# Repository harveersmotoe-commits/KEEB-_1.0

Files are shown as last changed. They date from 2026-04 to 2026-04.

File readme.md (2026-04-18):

# Description:

This is a 60% keyboard which also has a rotary encoder, 0.91 oled display, and 5 extra programmable buttons. This runs on a Raspberry Pi Pico and is not battery powered. 

Why did I make this?
In blueprint I had tried to make a split keyboard because in my opinion that is way cooler than this, the only thing being that it was kinda difficult without any piror knowledge. You can kind of spot the attempt in the schematics but, I did ditch it soon after. 

# Schematics



# PCB



# 3d Renders: 

https://cad.onshape.com/documents/1ae3be99bbc461a973191d69/w/fc64a29f0eed5ccd2d31274e/e/07f126c9bb32923463e6050c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

FRONT:



SIDE:



# Zine Fallout Page

# BOM



# CREDITS

Hack Club Fallout: For giving me this oppurtunity

Thanks to the Youtube Creator Flux (For the tips on how to make my PCB look presentable)

# How to Build

  Start off with the Raspberry Pi and Solider headers if not yet soldier, if you are a beginner I would highly recommend watching this video (https://youtu.be/Z0joOKaQ43A?si=yZU-sQ1wUjgkzB4q&t=37)

  Then add switches to all of the holes that ressemble hole puncher holes, making sure that the little copper lines aren't being jammed in the wrong way, this should be easy to put on with not much resistance.

  After doing this solder all the switches to the pcb and then follow with the Raspberry Pi Pico and resistors (Photo coming soon of where to put what)

  NOTE: FOR UNDERGLOW MAKE SURE YOU ORDER THE RIGHT PCB (ONE HAS NO SUPPORT) AND USE CLEAR FILAMENT FOR THE BOTTOM SHELL IF USING UNDERGLOW

  *If you have the PCB WHICH HAS UNDERGLOW SUPPORT MAKE SuRE YOU SOLDIER THE LEDS TO THE BOTTOM

  Then grab your 3d printed materials and use the screws to tighten the pcb to the bottom shell

  Use the magnets and add them onto both the bottom and top shell pieces.

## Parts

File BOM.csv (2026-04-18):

 |  | QTY | PRICE
Raspberry Pi: | https://www.alibaba.com/product-detail/Stock-original-Raspberry-Pi-Pico-W_1601212449258.html | 1 | $2.87
0.91 OLED: | https://www.aliexpress.us/item/3256806882812437.html | 1 | $2.15
Keycaps | https://www.alibaba.com/product-detail/Rene-Genger-129-Keys-Side-Printed_1601675107935.htmll | 1 | $9.28
Diodes | https://www.aliexpress.us/item/3256802153601411.html | 1 | $1.04
Buttons: | https://www.aliexpress.us/item/3256808426699412.html | 4 | $3.01
Stabillizers: | https://www.aliexpress.us/item/3256807026554334.html | 1 | $0.99
Capaciators: | https://www.aliexpress.us/item/3256807473764027.html | 1 | $0.99
LEDs; | https://www.aliexpress.us/item/2255801159561004.html | 1 | $0.99
Capacators: | https://www.aliexpress.us/item/3256802104127109.html | 1 | $1.30
PCB | I ORDERED FROM JLCPCB (CHEAPER THAN PCBWAY IN CALI) | 1 | $19.10
Plate (3D Printed) |  | 1 | N/A
Magnets: | https://www.aliexpress.us/item/3256811570240902.htmll | 1 | $0.99
Keyswitches | https://www.aliexpress.us/item/3256808499657735.html | 1 | $5.57
Shells (3D printed) |  | 1 | N/A
 |  | TOTAL | $59.59

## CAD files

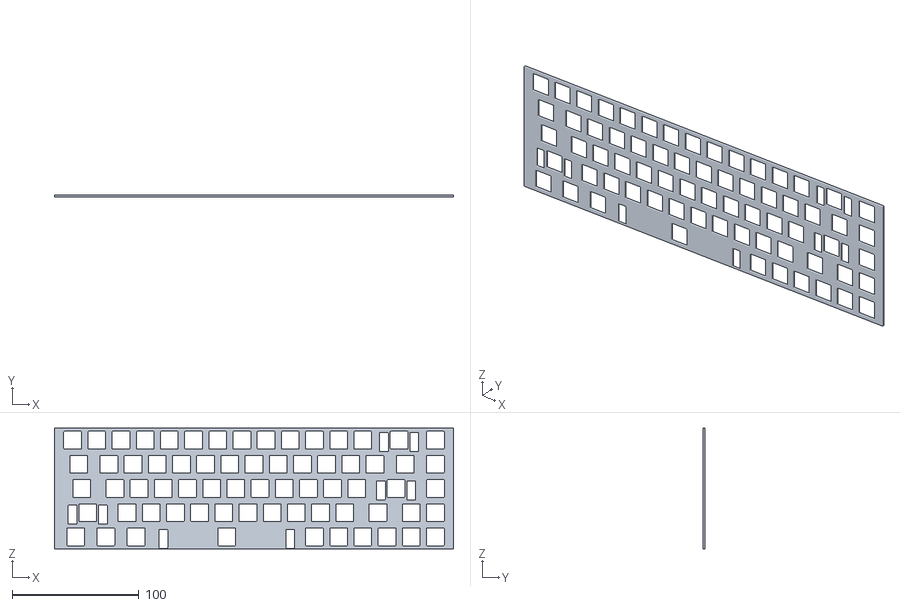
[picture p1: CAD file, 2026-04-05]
STLS/Keeb Plate.stl
314.3 x 1.60 x 95.2

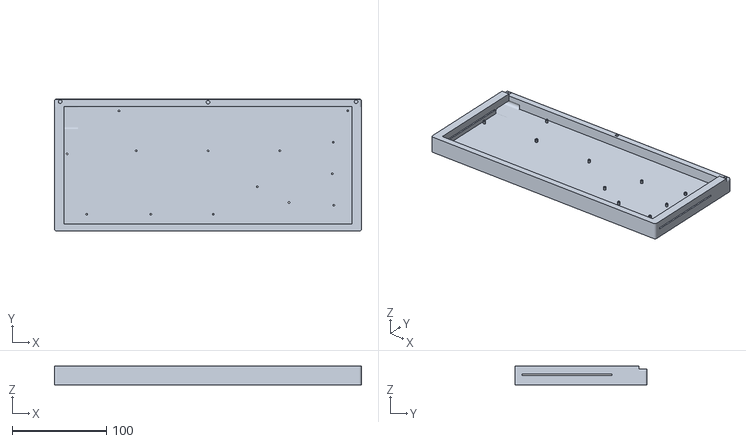
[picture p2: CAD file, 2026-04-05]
STLS/KeebBase.stl
325.0 x 140.0 x 20.0

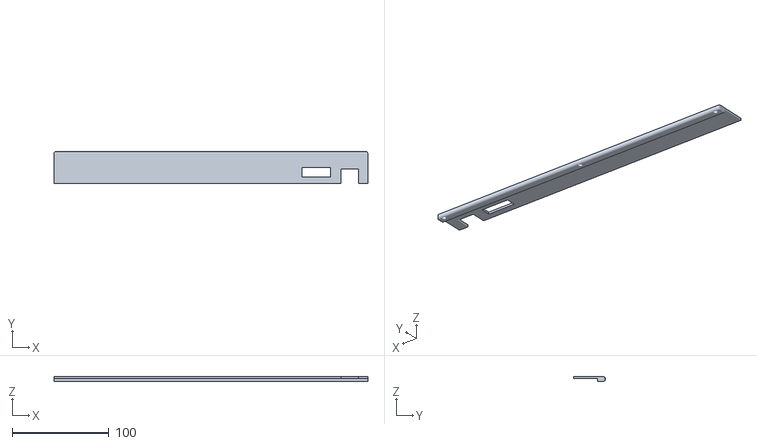
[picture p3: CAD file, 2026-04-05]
STLS/KEEBtop (1).stl
325.0 x 33.2 x 5.00

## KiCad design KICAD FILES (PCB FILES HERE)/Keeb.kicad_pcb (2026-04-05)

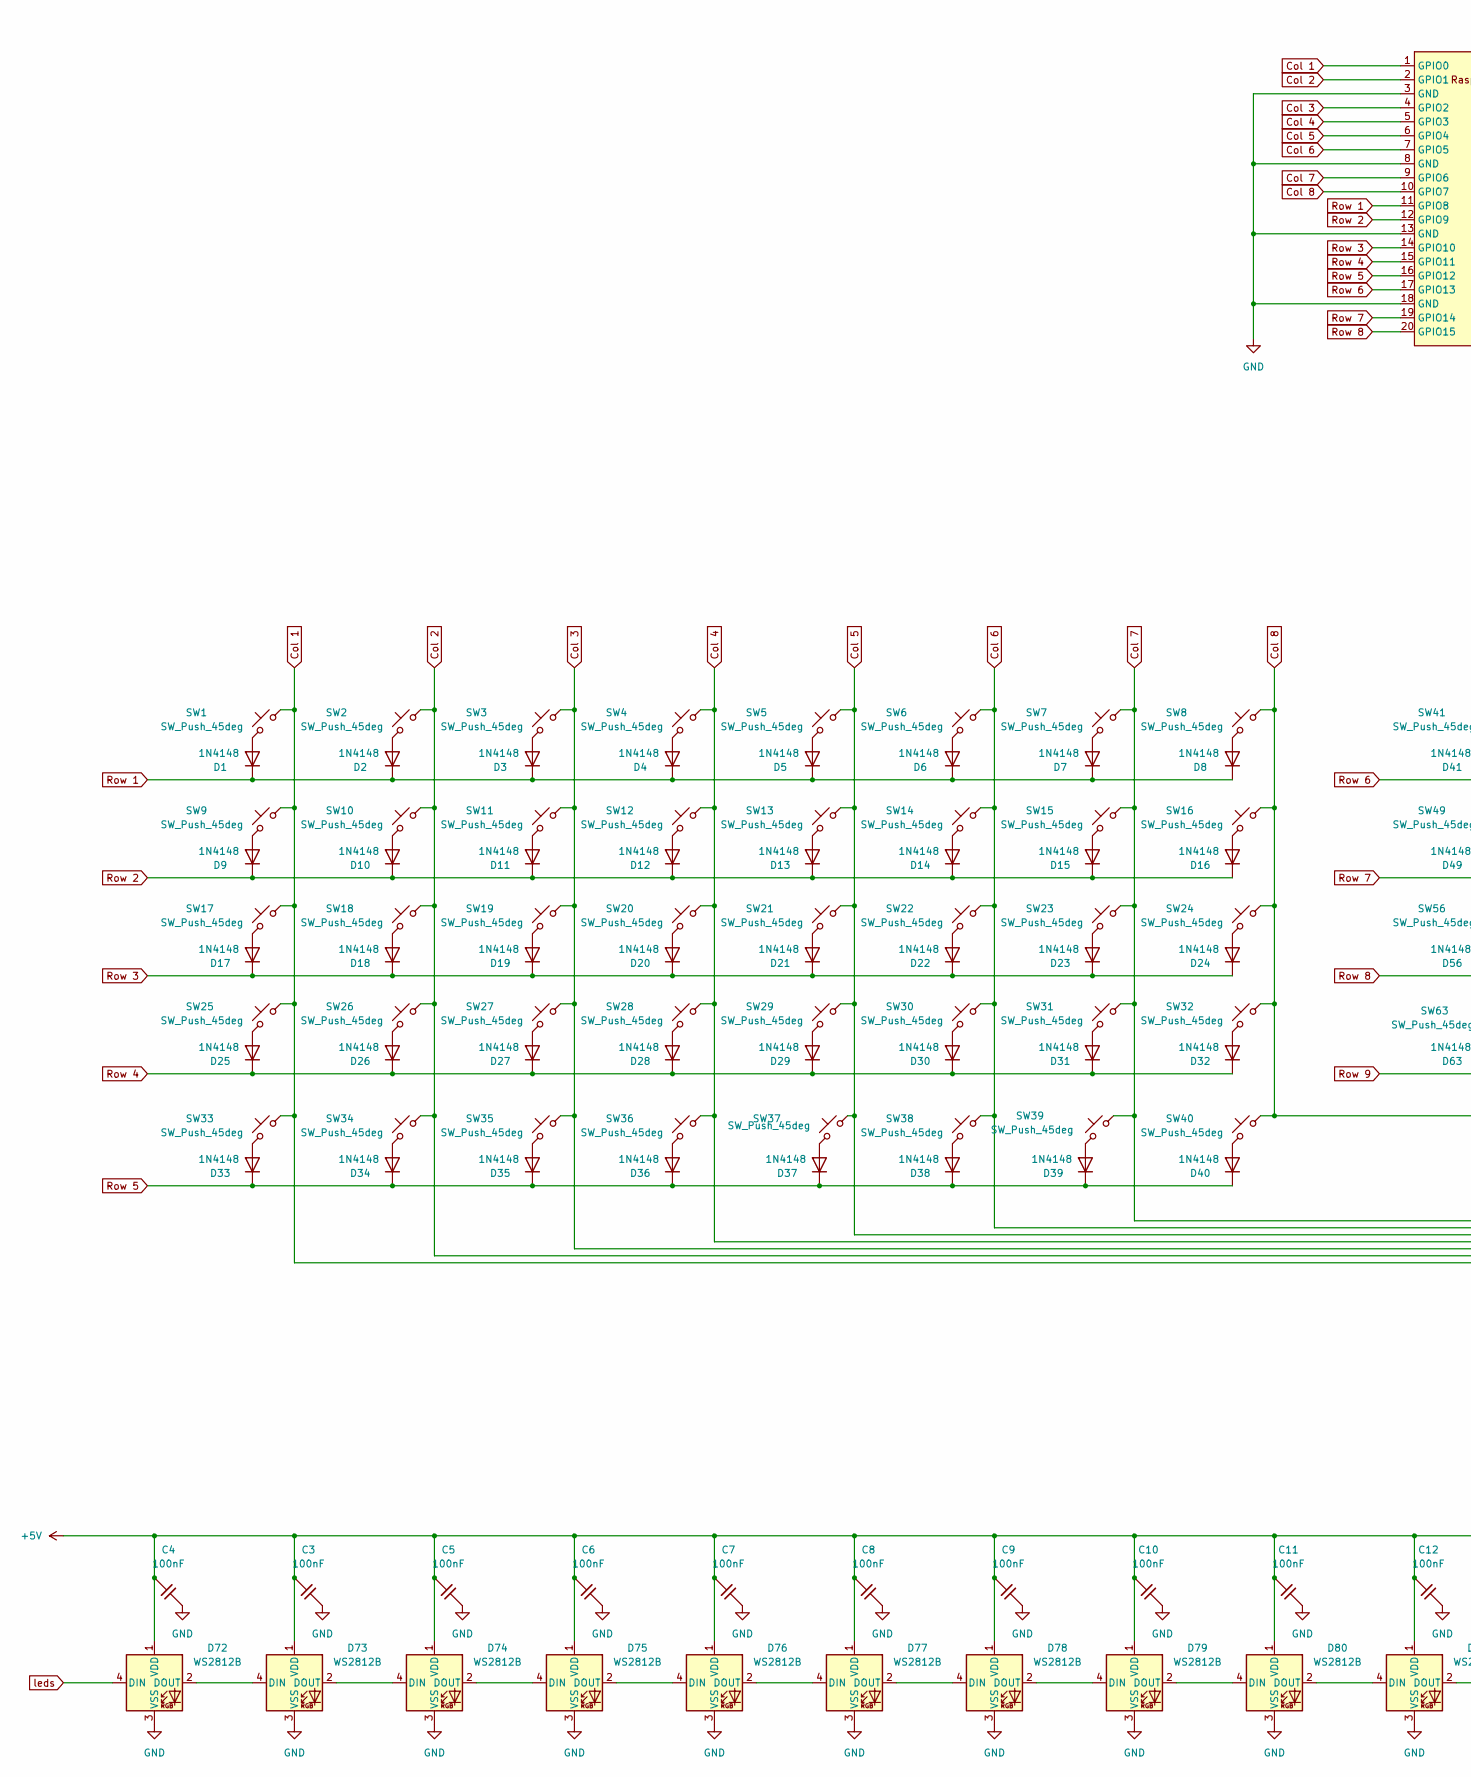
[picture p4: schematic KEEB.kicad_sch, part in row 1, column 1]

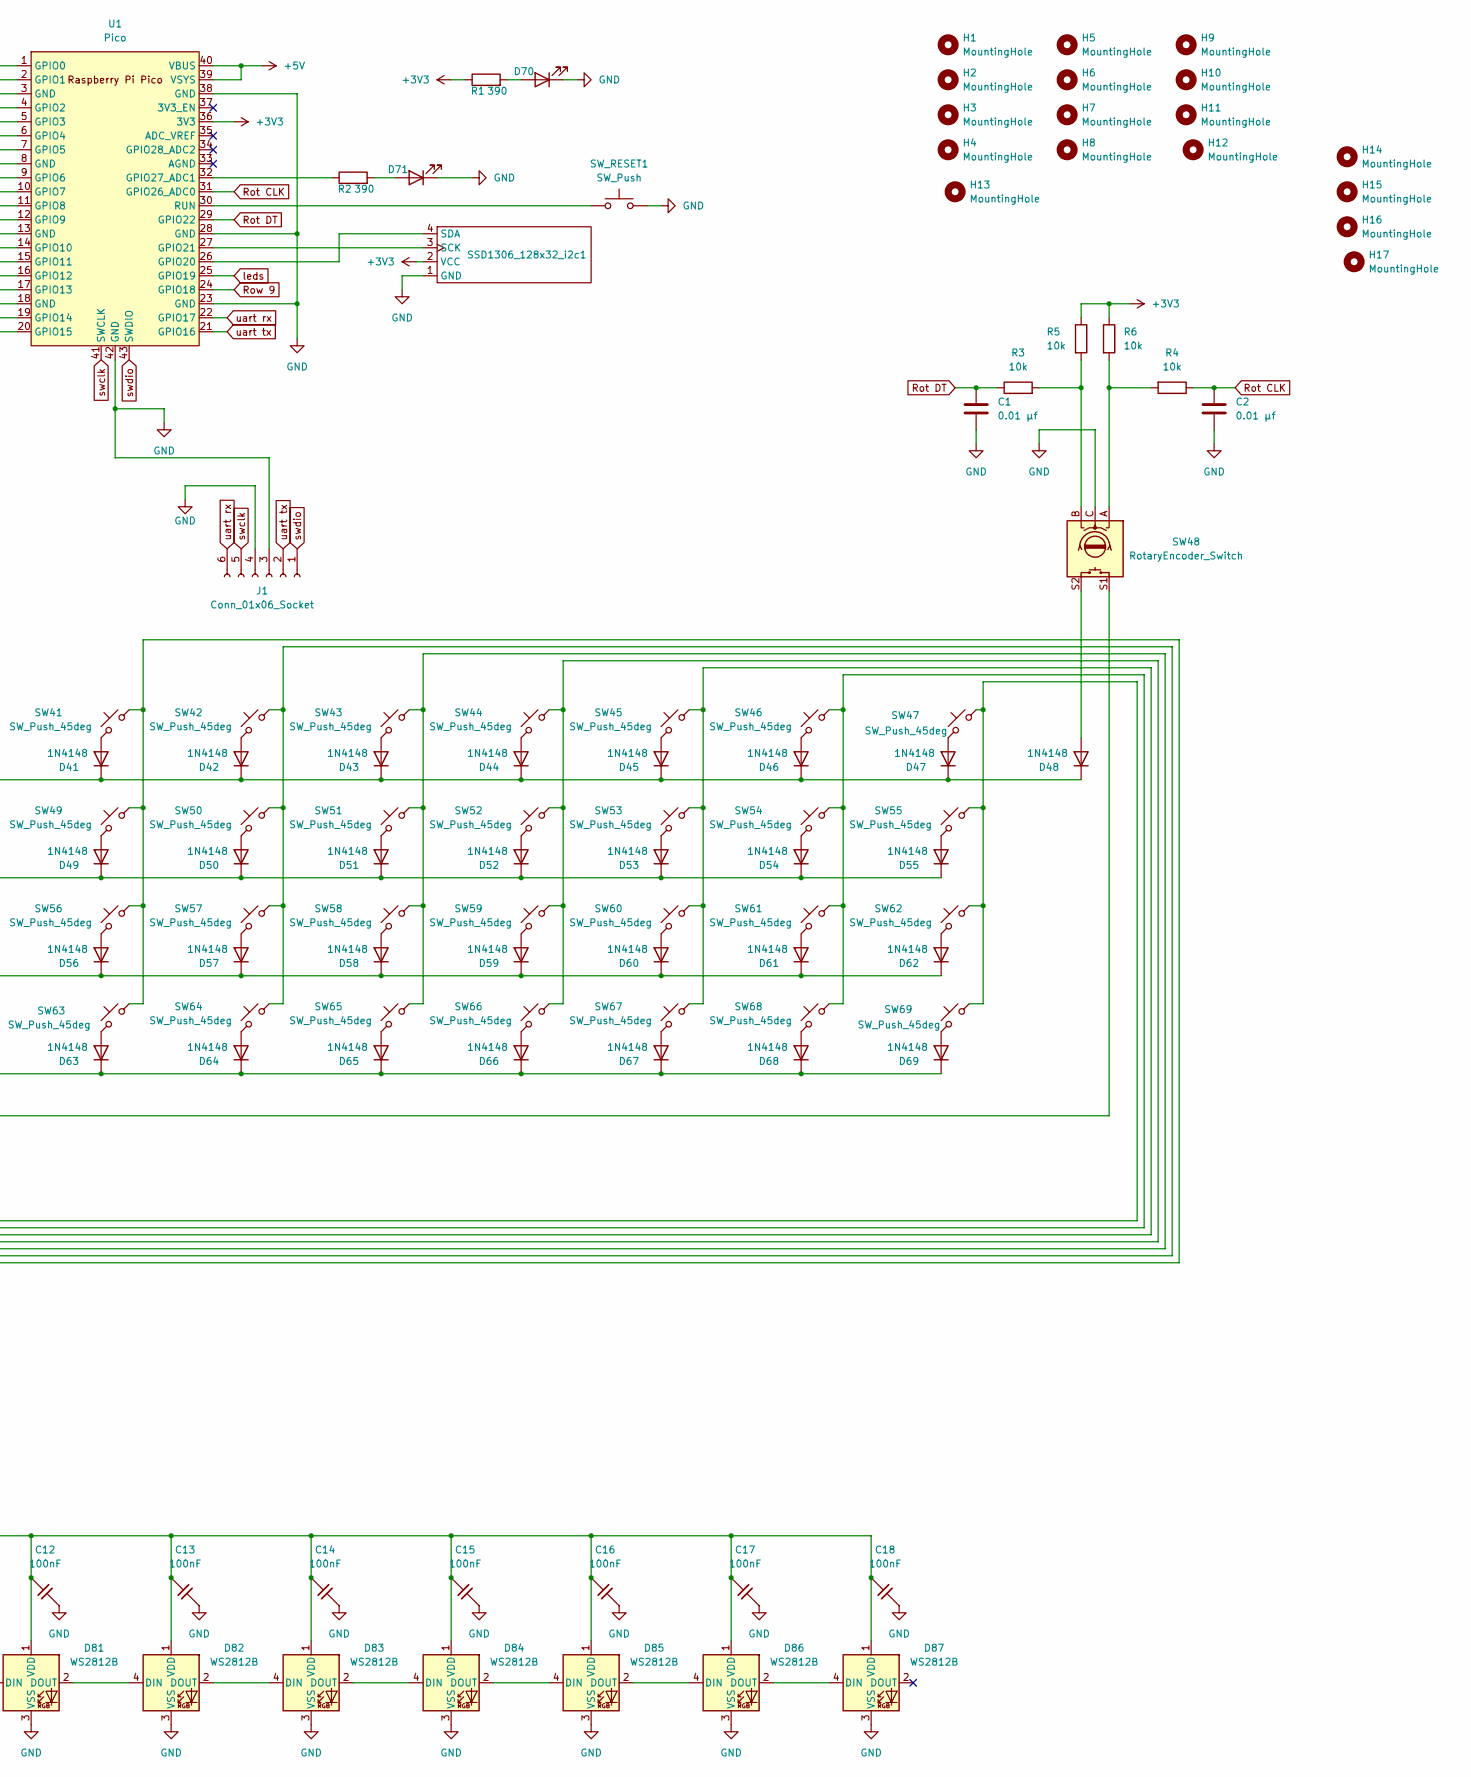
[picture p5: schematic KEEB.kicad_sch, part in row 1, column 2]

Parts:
C1, C2: 0.01 µf; C_Disc_D3.0mm_W1.6mm_P2.50mm
C3, C4, C5, C6, C7, C8, C9, C10, C11, C12, C13, C14, C15, C16, C17, C18: 100nF; C_0603_1608Metric
D1, D2, D3, D4, D5, D6, D7, D8, D9, D10, D11, D12, D13, D14, D15, D16, D17, D18, D19, D20, D21, D22, D23, D24, D25, D26, D27, D28, D29, D30, D31, D32, D33, D34, D35, D36, D37, D38, D39, D40, D41, D42, D43, D44, D45, D46, D47, D48, D49, D50, D51, D52, D53, D54, D55, D56, D57, D58, D59, D60, D61, D62, D63, D64, D65, D66, D67, D68, D69: 1N4148; D_DO-35_SOD27_P7.62mm_Horizontal
D70, D71: LED; LED_D5.0mm
D72, D73, D74, D75, D76, D77, D78, D79, D80, D81, D82, D83, D84, D85, D86, D87: WS2812B; LED_WS2812B_PLCC4_5.0x5.0mm_P3.2mm
H1, H2, H3, H4, H5, H6, H7, H8, H9, H10, H11, H12, H13, H14, H15, H16, H17: MountingHole; MountingHole_2.2mm_M2_Pad
J1: Conn_01x06_Socket; PinHeader_2x03_P2.54mm_Vertical
R1, R2: 390; R_Axial_DIN0207_L6.3mm_D2.5mm_P10.16mm_Horizontal
R3, R4, R5, R6: 10k; R_Axial_DIN0207_L6.3mm_D2.5mm_P10.16mm_Horizontal
SSD1306_128x32_i2c1: SSD1306_128x32_i2c
SW1, SW2, SW3, SW4, SW5, SW6, SW7, SW8, SW10, SW11, SW12, SW13, SW14, SW15, SW16, SW18, SW19, SW20, SW21, SW22, SW23, SW24, SW26, SW27, SW28, SW29, SW30, SW31, SW32, SW37, SW38, SW39, SW40, SW41, SW42, SW43, SW44, SW45, SW47, SW49, SW50, SW51, SW52, SW53, SW55, SW56, SW57, SW58, SW59, SW61, SW62, SW63, SW64, SW65, SW67, SW68, SW69: SW_Push_45deg; SW_Cherry_MX_PCB_1.00u
SW9, SW54: SW_Push_45deg; SW_Cherry_MX_PCB_1.50u
SW17, SW66: SW_Push_45deg; SW_Cherry_MX_PCB_1.75u
SW25, SW60: SW_Push_45deg; SW_Cherry_MX_PCB_2.25u
SW33, SW34, SW35: SW_Push_45deg; SW_Cherry_MX_PCB_1.25u
SW36: SW_Push_45deg; SW_Cherry_MX_PCB_6.25u
SW46: SW_Push_45deg; SW_Cherry_MX_PCB_2.00u
SW48: RotaryEncoder_Switch; RotaryEncoder_Alps_EC11E-Switch_Vertical_H20mm
SW_RESET1: SW_Push; SW_PUSH_6mm
U1: Pico; RPi_Pico_SMD_TH

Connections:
+3V3: R1.1, R5.1, R6.1, SSD1306_128x32_i2c1.2 (VCC), U1.36 (3V3); also elsewhere on the board
+5V: C3.2, C4.2, C5.2, C6.2, C7.2, C8.2, C9.2, C10.2, C11.2, C12.2, C13.2, C14.2, C15.2, C16.2, C17.2, C18.2, D72.1 (VDD), D73.1 (VDD), D74.1 (VDD), D75.1 (VDD), D76.1 (VDD), D77.1 (VDD), D78.1 (VDD), D79.1 (VDD), D80.1 (VDD), D81.1 (VDD), D82.1 (VDD), D83.1 (VDD), D84.1 (VDD), D85.1 (VDD), D86.1 (VDD), D87.1 (VDD), U1.39 (VSYS), U1.40 (VBUS); also elsewhere on the board
Col 1: SW1.2, SW9.2, SW17.2, SW25.2, SW33.2, SW41.2, SW49.2, SW56.2, SW63.2, U1.1 (GPIO0); also elsewhere on the board
Col 2: SW2.2, SW10.2, SW18.2, SW26.2, SW34.2, SW42.2, SW50.2, SW57.2, SW64.2, U1.2 (GPIO1); also elsewhere on the board
Col 3: SW3.2, SW11.2, SW19.2, SW27.2, SW35.2, SW43.2, SW51.2, SW58.2, SW65.2, U1.4 (GPIO2); also elsewhere on the board
Col 4: SW4.2, SW12.2, SW20.2, SW28.2, SW36.2, SW44.2, SW52.2, SW59.2, SW66.2, U1.5 (GPIO3); also elsewhere on the board
Col 5: SW5.2, SW13.2, SW21.2, SW29.2, SW37.2, SW45.2, SW53.2, SW60.2, SW67.2, U1.6 (GPIO4); also elsewhere on the board
Col 6: SW6.2, SW14.2, SW22.2, SW30.2, SW38.2, SW46.2, SW54.2, SW61.2, SW68.2, U1.7 (GPIO5); also elsewhere on the board
Col 7: SW7.2, SW15.2, SW23.2, SW31.2, SW39.2, SW47.2, SW55.2, SW62.2, SW69.2, U1.9 (GPIO6); also elsewhere on the board
Col 8: SW8.2, SW16.2, SW24.2, SW32.2, SW40.2, SW48.S1, U1.10 (GPIO7); also elsewhere on the board
GND: C1.2, C2.2, C3.1, C4.1, C5.1, C6.1, C7.1, C8.1, C9.1, C10.1, C11.1, C12.1, C13.1, C14.1, C15.1, C16.1, C17.1, C18.1, D70.1 (K), D71.1 (K), D72.3 (VSS), D73.3 (VSS), D74.3 (VSS), D75.3 (VSS), D76.3 (VSS), D77.3 (VSS), D78.3 (VSS), D79.3 (VSS), D80.3 (VSS), D81.3 (VSS), D82.3 (VSS), D83.3 (VSS), D84.3 (VSS), D85.3 (VSS), D86.3 (VSS), D87.3 (VSS), J1.3, J1.4, SSD1306_128x32_i2c1.1 (GND), SW48.C, SW_RESET1.2, U1.3 (GND), U1.8 (GND), U1.13 (GND), U1.18 (GND), U1.23 (GND), U1.28 (GND), U1.38 (GND), U1.42 (GND); also elsewhere on the board
unnamed: D1.2 (A), SW1.1
unnamed: D2.2 (A), SW2.1
unnamed: D3.2 (A), SW3.1
unnamed: D4.2 (A), SW4.1
unnamed: D5.2 (A), SW5.1
unnamed: D6.2 (A), SW6.1
unnamed: D7.2 (A), SW7.1
unnamed: D8.2 (A), SW8.1
unnamed: D9.2 (A), SW9.1
unnamed: D10.2 (A), SW10.1
unnamed: D11.2 (A), SW11.1
unnamed: D12.2 (A), SW12.1
unnamed: D13.2 (A), SW13.1
unnamed: D14.2 (A), SW14.1
unnamed: D15.2 (A), SW15.1
unnamed: D16.2 (A), SW16.1
unnamed: D17.2 (A), SW17.1
unnamed: D18.2 (A), SW18.1
unnamed: D19.2 (A), SW19.1
unnamed: D20.2 (A), SW20.1
unnamed: D21.2 (A), SW21.1
unnamed: D22.2 (A), SW22.1
unnamed: D23.2 (A), SW23.1
unnamed: D24.2 (A), SW24.1
unnamed: D25.2 (A), SW25.1
unnamed: D26.2 (A), SW26.1
unnamed: D27.2 (A), SW27.1
unnamed: D28.2 (A), SW28.1
unnamed: D29.2 (A), SW29.1
unnamed: D30.2 (A), SW30.1
unnamed: D31.2 (A), SW31.1
unnamed: D32.2 (A), SW32.1
unnamed: D33.2 (A), SW33.1
unnamed: D34.2 (A), SW34.1
unnamed: D35.2 (A), SW35.1
unnamed: D36.2 (A), SW36.1
unnamed: D37.2 (A), SW37.1
unnamed: D38.2 (A), SW38.1
unnamed: D39.2 (A), SW39.1
unnamed: D40.2 (A), SW40.1
unnamed: D41.2 (A), SW41.1
unnamed: D42.2 (A), SW42.1
unnamed: D43.2 (A), SW43.1
unnamed: D44.2 (A), SW44.1
unnamed: D45.2 (A), SW45.1
unnamed: D46.2 (A), SW46.1
unnamed: D47.2 (A), SW47.1
unnamed: D48.2 (A), SW48.S2
unnamed: D49.2 (A), SW49.1
unnamed: D50.2 (A), SW50.1
unnamed: D51.2 (A), SW51.1
unnamed: D52.2 (A), SW52.1
unnamed: D53.2 (A), SW53.1
unnamed: D54.2 (A), SW54.1
unnamed: D55.2 (A), SW55.1
unnamed: D56.2 (A), SW56.1
unnamed: D57.2 (A), SW57.1
unnamed: D58.2 (A), SW58.1
unnamed: D59.2 (A), SW59.1
unnamed: D60.2 (A), SW60.1
unnamed: D61.2 (A), SW61.1
unnamed: D62.2 (A), SW62.1
unnamed: D63.2 (A), SW63.1
unnamed: D64.2 (A), SW64.1
unnamed: D65.2 (A), SW65.1
unnamed: D66.2 (A), SW66.1
unnamed: D67.2 (A), SW67.1
unnamed: D68.2 (A), SW68.1
unnamed: D69.2 (A), SW69.1
unnamed: D70.2 (A), R1.2
unnamed: D71.2 (A), R2.2
unnamed: D72.2 (DOUT), D73.4 (DIN)
unnamed: D73.2 (DOUT), D74.4 (DIN)
unnamed: D74.2 (DOUT), D75.4 (DIN)
unnamed: D75.2 (DOUT), D76.4 (DIN)
unnamed: D76.2 (DOUT), D77.4 (DIN)
unnamed: D77.2 (DOUT), D78.4 (DIN)
unnamed: D78.2 (DOUT), D79.4 (DIN)
unnamed: D79.2 (DOUT), D80.4 (DIN)
unnamed: D80.2 (DOUT), D81.4 (DIN)
unnamed: D81.2 (DOUT), D82.4 (DIN)
unnamed: D82.2 (DOUT), D83.4 (DIN)
unnamed: D83.2 (DOUT), D84.4 (DIN)
unnamed: D84.2 (DOUT), D85.4 (DIN)
unnamed: D85.2 (DOUT), D86.4 (DIN)
unnamed: D86.2 (DOUT), D87.4 (DIN)
unnamed: R3.2, R5.2, SW48.B
unnamed: R4.2, R6.2, SW48.A
unnamed 99: SSD1306_128x32_i2c1.3 (SCK), U1.27 (GPIO21); also elsewhere on the board
unnamed 100: SSD1306_128x32_i2c1.4 (SDA), U1.26 (GPIO20); also elsewhere on the board
unnamed: SW_RESET1.1, U1.30 (RUN)
unnamed 102: R2.1, U1.32 (GPIO27_ADC1); also elsewhere on the board
Rot CLK: C2.1, R4.1, U1.31 (GPIO26_ADC0); also elsewhere on the board
Rot DT: C1.1, R3.1, U1.29 (GPIO22); also elsewhere on the board
Row 1: D1.1 (K), D2.1 (K), D3.1 (K), D4.1 (K), D5.1 (K), D6.1 (K), D7.1 (K), D8.1 (K), U1.11 (GPIO8); also elsewhere on the board
Row 2: D9.1 (K), D10.1 (K), D11.1 (K), D12.1 (K), D13.1 (K), D14.1 (K), D15.1 (K), D16.1 (K), U1.12 (GPIO9); also elsewhere on the board
Row 3: D17.1 (K), D18.1 (K), D19.1 (K), D20.1 (K), D21.1 (K), D22.1 (K), D23.1 (K), D24.1 (K), U1.14 (GPIO10); also elsewhere on the board
Row 4: D25.1 (K), D26.1 (K), D27.1 (K), D28.1 (K), D29.1 (K), D30.1 (K), D31.1 (K), D32.1 (K), U1.15 (GPIO11); also elsewhere on the board
Row 5: D33.1 (K), D34.1 (K), D35.1 (K), D36.1 (K), D37.1 (K), D38.1 (K), D39.1 (K), D40.1 (K), U1.16 (GPIO12); also elsewhere on the board
Row 6: D41.1 (K), D42.1 (K), D43.1 (K), D44.1 (K), D45.1 (K), D46.1 (K), D47.1 (K), D48.1 (K), U1.17 (GPIO13); also elsewhere on the board
Row 7: D49.1 (K), D50.1 (K), D51.1 (K), D52.1 (K), D53.1 (K), D54.1 (K), D55.1 (K), U1.19 (GPIO14); also elsewhere on the board
Row 8: D56.1 (K), D57.1 (K), D58.1 (K), D59.1 (K), D60.1 (K), D61.1 (K), D62.1 (K), U1.20 (GPIO15); also elsewhere on the board
Row 9: D63.1 (K), D64.1 (K), D65.1 (K), D66.1 (K), D67.1 (K), D68.1 (K), D69.1 (K), U1.24 (GPIO18); also elsewhere on the board
leds: D72.4 (DIN), U1.25 (GPIO19); also elsewhere on the board
swclk: J1.5, U1.41 (SWCLK); also elsewhere on the board
swdio: J1.1, U1.43 (SWDIO); also elsewhere on the board
uart rx: J1.6, U1.22 (GPIO17); also elsewhere on the board
uart tx: J1.2, U1.21 (GPIO16); also elsewhere on the board

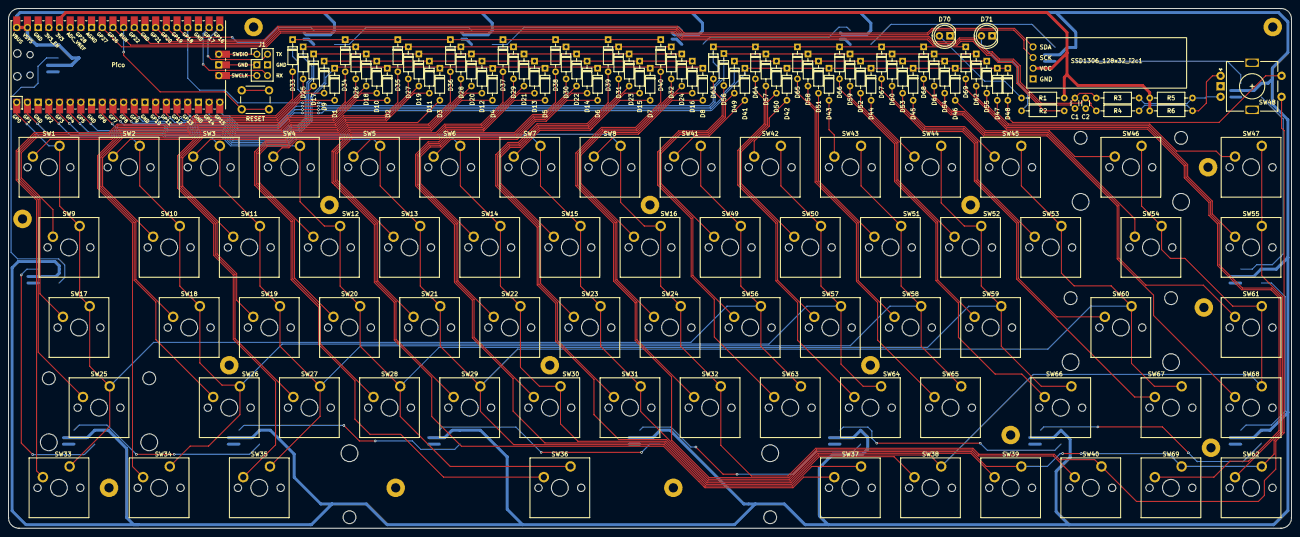
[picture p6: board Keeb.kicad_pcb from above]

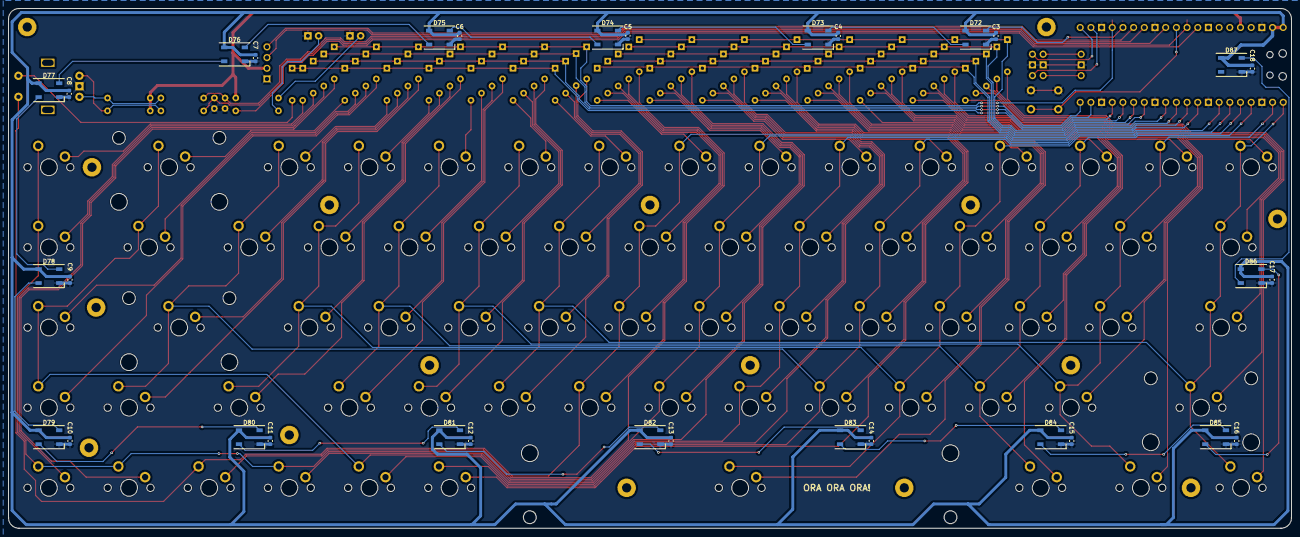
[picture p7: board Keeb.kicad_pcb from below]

Board: 2 copper layers, 305.0 x 123.5 mm, 200 parts (32 on the bottom side), 119 nets.

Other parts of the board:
Pico: Pico; RPi_Pico_SMD_TH
RESET: SW_Push; SW_PUSH_6mm

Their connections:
+3V3: Pico.36 (3V3); also elsewhere on the board
+5V: Pico.39 (VSYS), Pico.40 (VBUS); also elsewhere on the board
Col 1: Pico.1 (GPIO0); also elsewhere on the board
Col 2: Pico.2 (GPIO1); also elsewhere on the board
Col 3: Pico.4 (GPIO2); also elsewhere on the board
Col 4: Pico.5 (GPIO3); also elsewhere on the board
Col 5: Pico.6 (GPIO4); also elsewhere on the board
Col 6: Pico.7 (GPIO5); also elsewhere on the board
Col 7: Pico.9 (GPIO6); also elsewhere on the board
Col 8: Pico.10 (GPIO7); also elsewhere on the board
GND: Pico.3 (GND), Pico.8 (GND), Pico.13 (GND), Pico.18 (GND), Pico.23 (GND), Pico.28 (GND), Pico.38 (GND), Pico.42 (GND), RESET.2; also elsewhere on the board
unnamed 99: Pico.27 (GPIO21); also elsewhere on the board
unnamed 100: Pico.26 (GPIO20); also elsewhere on the board
unnamed 102: Pico.32 (GPIO27_ADC1); also elsewhere on the board
unnamed: Pico.30 (RUN), RESET.1
Rot CLK: Pico.31 (GPIO26_ADC0); also elsewhere on the board
Rot DT: Pico.29 (GPIO22); also elsewhere on the board
Row 1: Pico.11 (GPIO8); also elsewhere on the board
Row 2: Pico.12 (GPIO9); also elsewhere on the board
Row 3: Pico.14 (GPIO10); also elsewhere on the board
Row 4: Pico.15 (GPIO11); also elsewhere on the board
Row 5: Pico.16 (GPIO12); also elsewhere on the board
Row 6: Pico.17 (GPIO13); also elsewhere on the board
Row 7: Pico.19 (GPIO14); also elsewhere on the board
Row 8: Pico.20 (GPIO15); also elsewhere on the board
Row 9: Pico.24 (GPIO18); also elsewhere on the board
leds: Pico.25 (GPIO19); also elsewhere on the board
swclk: Pico.41 (SWCLK); also elsewhere on the board
swdio: Pico.43 (SWDIO); also elsewhere on the board
uart rx: Pico.22 (GPIO17); also elsewhere on the board
uart tx: Pico.21 (GPIO16); also elsewhere on the board

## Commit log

2026-04-05 Updated CSV
    [BOM_ Keeb - Sheet1 (2).csv, BOM_ Keeb - Sheet1.csv]
2026-04-05 moved to stl file
    [KEEBtop (1).stl, Keeb Plate.stl, KeebBase.stl]
2026-04-05 ADDED PCBs
    [KEEB.kicad_sch]
2026-04-18 ADDED KICAD FILES
    [KEEB.kicad_sch, Keeb.kicad_pcb]
2026-04-18 UPDATED BOM
    [BOM.csv, BOM_ Keeb - Sheet1 (1).csv]
2026-04-18 kicad stuff
    [KEEB.kicad_sch, Keeb.kicad_pcb]
